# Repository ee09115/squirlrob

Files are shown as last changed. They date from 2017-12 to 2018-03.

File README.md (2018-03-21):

# [SquirlRob](https://github.com/ee09115/squirlrob)

## Overview
SquirRob is a 25 euros Android and Arduino based mobile robot for robotics education. The mechanical and electronic designs are provided and it is expected for the students to improve them. The android application uses the rear camera and implements some image processing modules allowing actions such as coloured line following, colour proximity detection and coloured object tracking.

* Conference Paper - [SQUIRLROB: A DO IT YOURSELF ARDUINO AND SMARTPHONE HARDWARE AND SOFTWARE PLATFORMS FOR ROBOTICS EDUCATION](https://doi.org/10.21125/inted.2018.1068)

<p align="center">

</p>

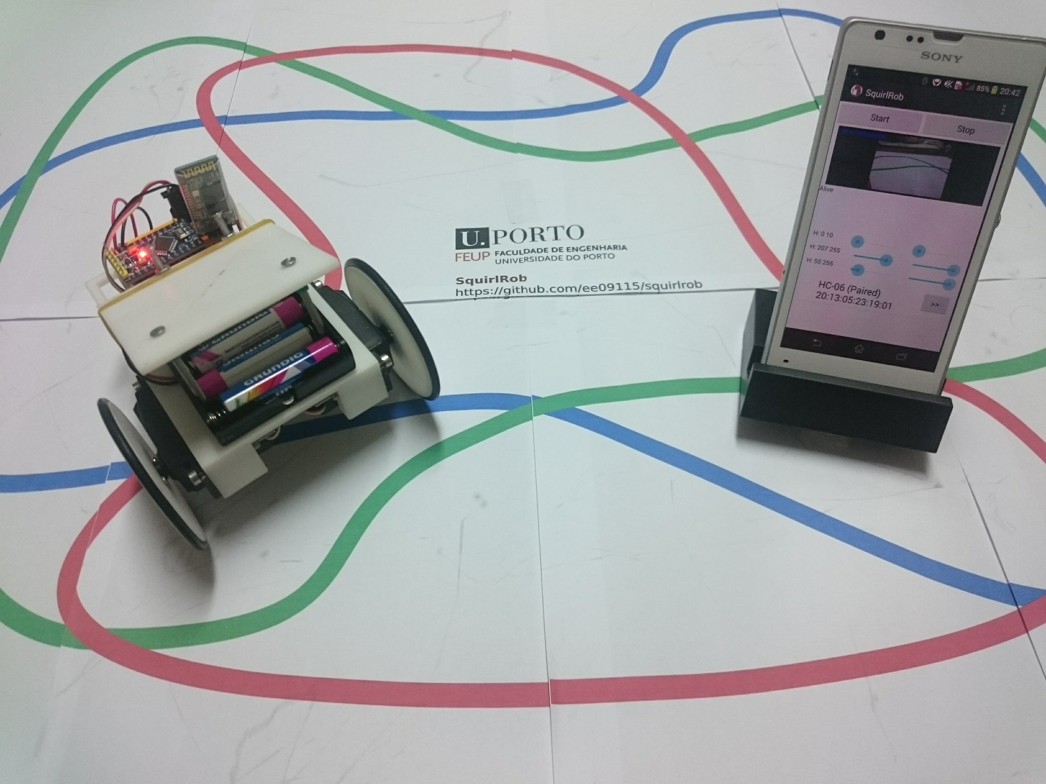
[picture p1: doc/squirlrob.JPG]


## Electronic Parts List
* HC-06 Bluetooth Module - [Ebay link](https://www.ebay.com/itm/1PCS-Slave-HC-06-Wireless-Bluetooth-Transeiver-RF-Master-Module-for-Arduino/201415076859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)
* Arduino Pro Mini 3V3@8MHz - [Ebay link](https://www.ebay.com/itm/1PCS-Mini-ATMEAG328-3-3V-8Mhz-Replace-ATmega128-For-Arduino-Pro-Mini-Compatible/152110232869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)
* Batery Holder - [Ebay link](https://www.ebay.com/itm/New-1PC-4-AAA-Battery-1-5V-Holder-Box-Case-Storage-DIY-Test-Study-Tool-Converter/201105132105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)
* Futaba S3003 Servo Motor - [Ebay link](https://www.ebay.com/itm/Big-Torque-Futaba-S3003-Servo-Motor-Metal-Gear-for-RC-Helicopter-Robot-Align-T-R/222649123161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)
* Mini Breadboard - [Ebay link](https://www.ebay.com/itm/Mini-Solderless-Prototype-Breadboard-170-Tie-points-For-Arduino/302120030495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)

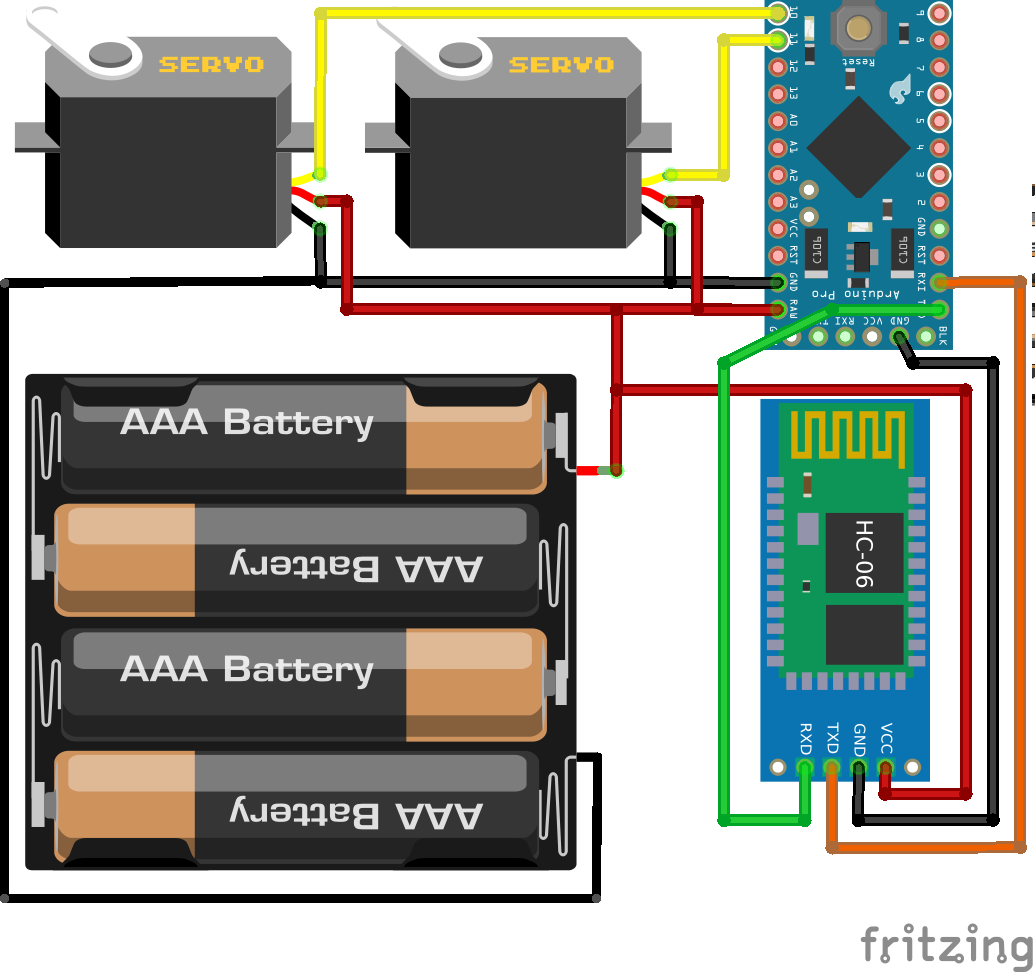
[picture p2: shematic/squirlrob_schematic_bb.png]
schematic


## Chassis
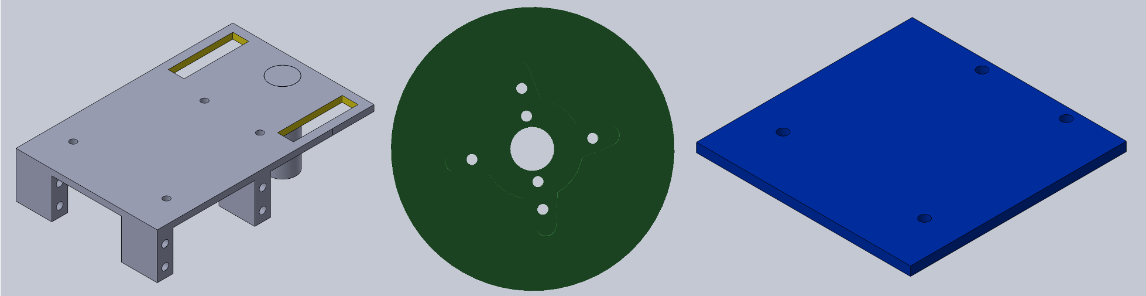
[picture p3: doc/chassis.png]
chassis


## Android Application
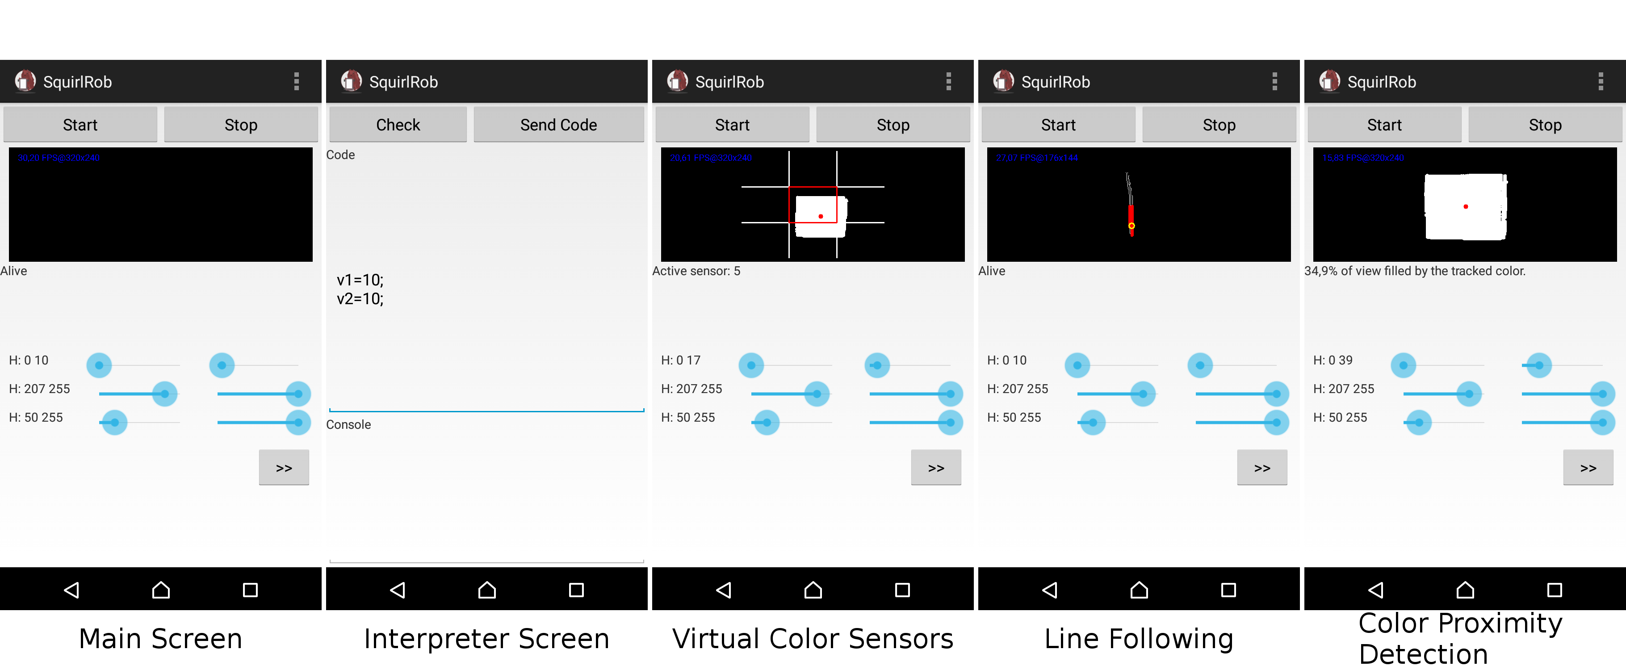
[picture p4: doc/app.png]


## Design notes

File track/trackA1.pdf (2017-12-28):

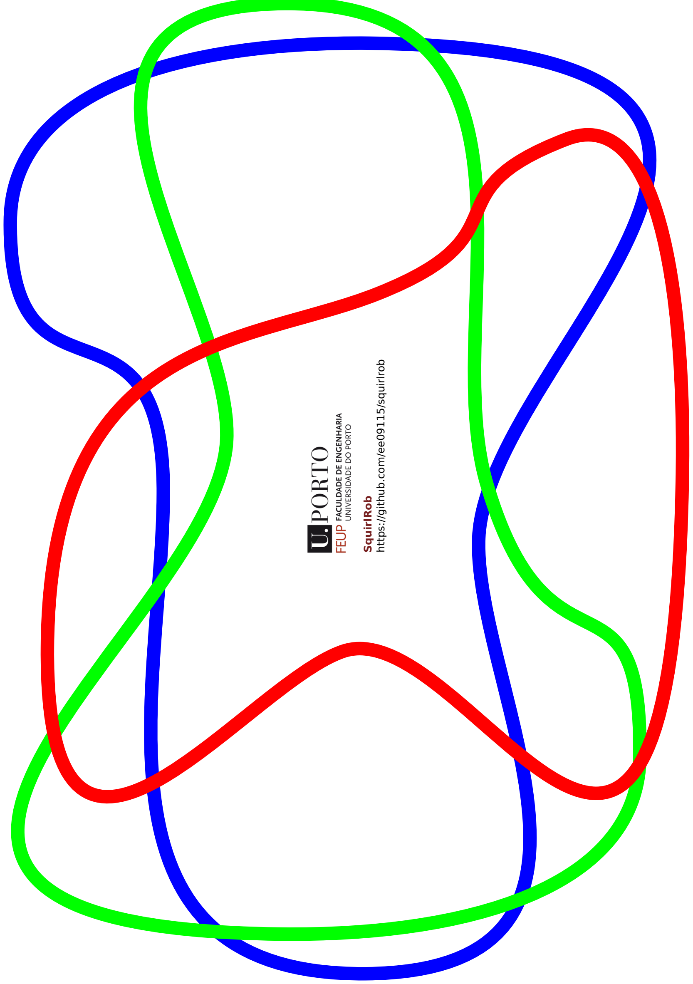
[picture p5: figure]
SquirlRob; https://github.com/ee09115/squirlrob

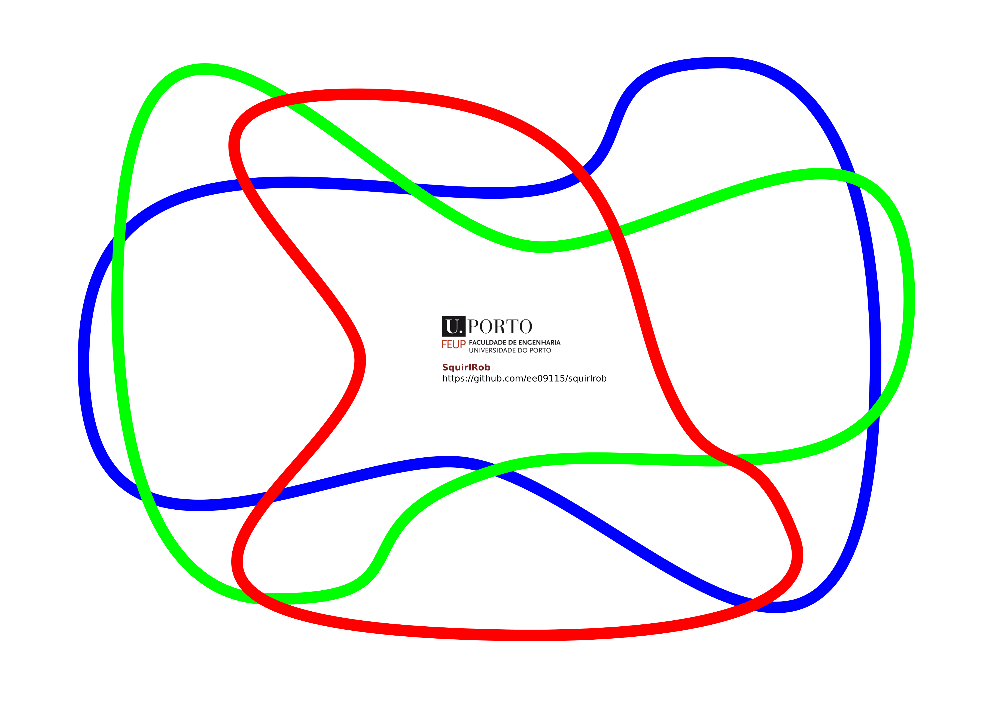
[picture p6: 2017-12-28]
track/SquirlRobTrack.png

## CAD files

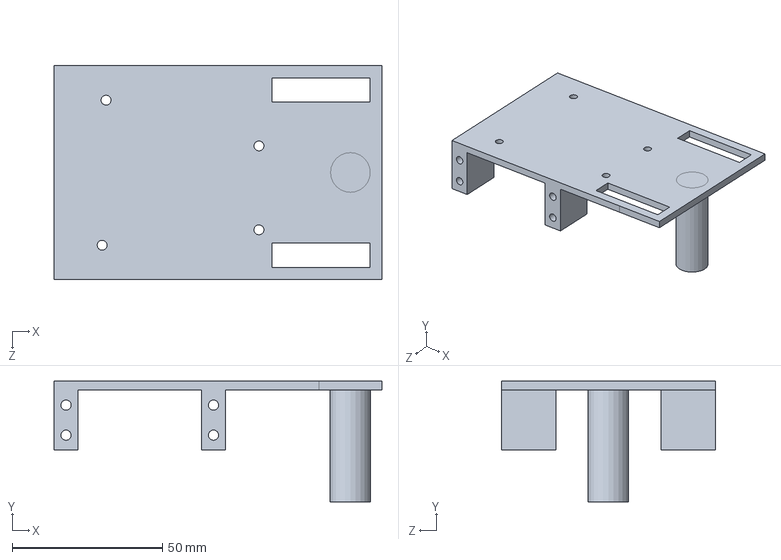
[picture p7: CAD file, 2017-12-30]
cad_files/chassis.SLDPRT
109.0 x 40.2 x 71.0 mm

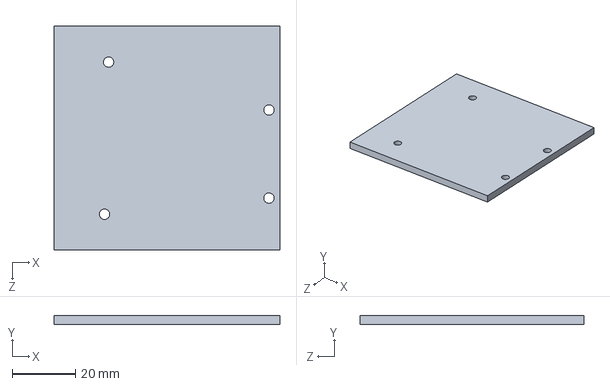
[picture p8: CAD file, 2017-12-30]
cad_files/support.SLDPRT
71.6 x 3.00 x 71.0 mm

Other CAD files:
cad_files/wheel.SLDPRT
stl_files/chassis.STL
stl_files/support.STL
stl_files/wheel.STL

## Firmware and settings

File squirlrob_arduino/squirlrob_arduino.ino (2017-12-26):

#include <Servo.h>

#define MOTOR_LEFT_ZERO  39
#define MOTOR_RIGHT_ZERO 70

#define SCALE(value,zero) ((zero) == MOTOR_RIGHT_ZERO ? -(value)*80/510+MOTOR_RIGHT_ZERO : (value)*80/510+MOTOR_LEFT_ZERO)

Servo left_servo,right_servo;

void setup() 
{
  // Servos Initialization
  left_servo.attach(11);//71
  right_servo.attach(10);//40
  
  // Initialize Serial Port
  Serial.begin(9600);
  Serial.setTimeout(1000);
  
  // Set velocities to zero
  left_servo.write(SCALE(0,MOTOR_LEFT_ZERO));
  right_servo.write(SCALE(0,MOTOR_RIGHT_ZERO)); 
}

void loop()
{
  int v11 = 0, v22 = 0;
  char buf= -0x01; 
  Serial.readBytes(&buf,1);
  
  char parity, end1, end2;
  switch(buf)
  {
    case -0x01:
      // Set servo velocities to zero
      left_servo.write(SCALE(0,MOTOR_LEFT_ZERO));
      right_servo.write(SCALE(0,MOTOR_RIGHT_ZERO));
    break;
    case 0x00:
      char control;
      Serial.readBytes(&control,1);
      Serial.readBytes(&parity,1);
      Serial.readBytes(&end1,1);
      Serial.readBytes(&end2,1);
      //Serial.print(int(control));
    break;
    case 0x01:
      char v1, v2;
      Serial.readBytes(&v1,1);
      Serial.readBytes(&v2,1);
      Serial.readBytes(&parity,1);
      Serial.readBytes(&end1,1);
      Serial.readBytes(&end2,1);
      //Serial.print(int(v1));
      //Serial.print(' ');
      //Serial.println(int(v2));
      v11 = (v1 * (255/128.0));
      v22 = (v2 * (255/128.0));
      v11 = SCALE(v11,MOTOR_LEFT_ZERO);
      v22 = SCALE(v22,MOTOR_RIGHT_ZERO);
      left_servo.write(v11);
      right_servo.write(v22);
    break;
    case 0x02:
      char bumper;
      Serial.readBytes(&control,1);
      Serial.readBytes(&parity,1);
      Serial.readBytes(&end1,1);
      Serial.readBytes(&end2,1);
      //Serial.print(int(bumper));
    break;
    default:
    break;
  }
}

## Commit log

2017-12-26 Added arduino code for SquirlRob
2017-12-28 Added track example
2017-12-28 Added schematic
    [squirlrob_schematic.fzz]
2017-12-30 Added CAD and STL files for the mobile robot
    [chassis.SLDPRT, chassis.STL, support.SLDPRT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]
2018-01-06 Added chassis pictures
